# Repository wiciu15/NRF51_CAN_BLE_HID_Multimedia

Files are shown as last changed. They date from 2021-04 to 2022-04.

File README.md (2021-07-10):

#### *TLDR: Controlling spotify on the phone, with car's CAN bus*

This project is a ***work in progress***. Comes with no warranty. Vehicles CAN-bus is a powerful tool, ***use at your own risk***, author does not have responsibility for any damage on property or health.

Intended for ***2011-2013 Chevrolet Volt***, may work with other General Motors Global Platform A cars.
Uses own ***MCP2515 CAN controller*** chip library to interact with CAN-bus (Low-speed SWCAN/GMLAN in General Motors Vehicles).

Nordic ***NRF51822 microcontroler*** is in charge of Bluetooth LE connection and HID protocol.
HID report descriptor is custom and supports only 7 consumer control(multimedia) keys, like Play/Pause, Scan Next, Scan Prev, Mute.

CAN frames processing is offloaded to MCP2515 with usage of filters, to reduce uC usage and energy efficiency.
While MCP2515 is used in normal operating mode, device should not transmit anything other than error/ack frames.

PCB design needs some fixes and further testing. As of this moment 16Mhz crystal footprint is mirrored, MCP2515 INT pin needs a pullup resistor and SWDIO/RST pullup+optional power-on-reset 2.2u capacitor.

**[Project log on hackaday.io](https://hackaday.io/project/176834-chevy-volt-sw-can-ble-multimedia-control)**

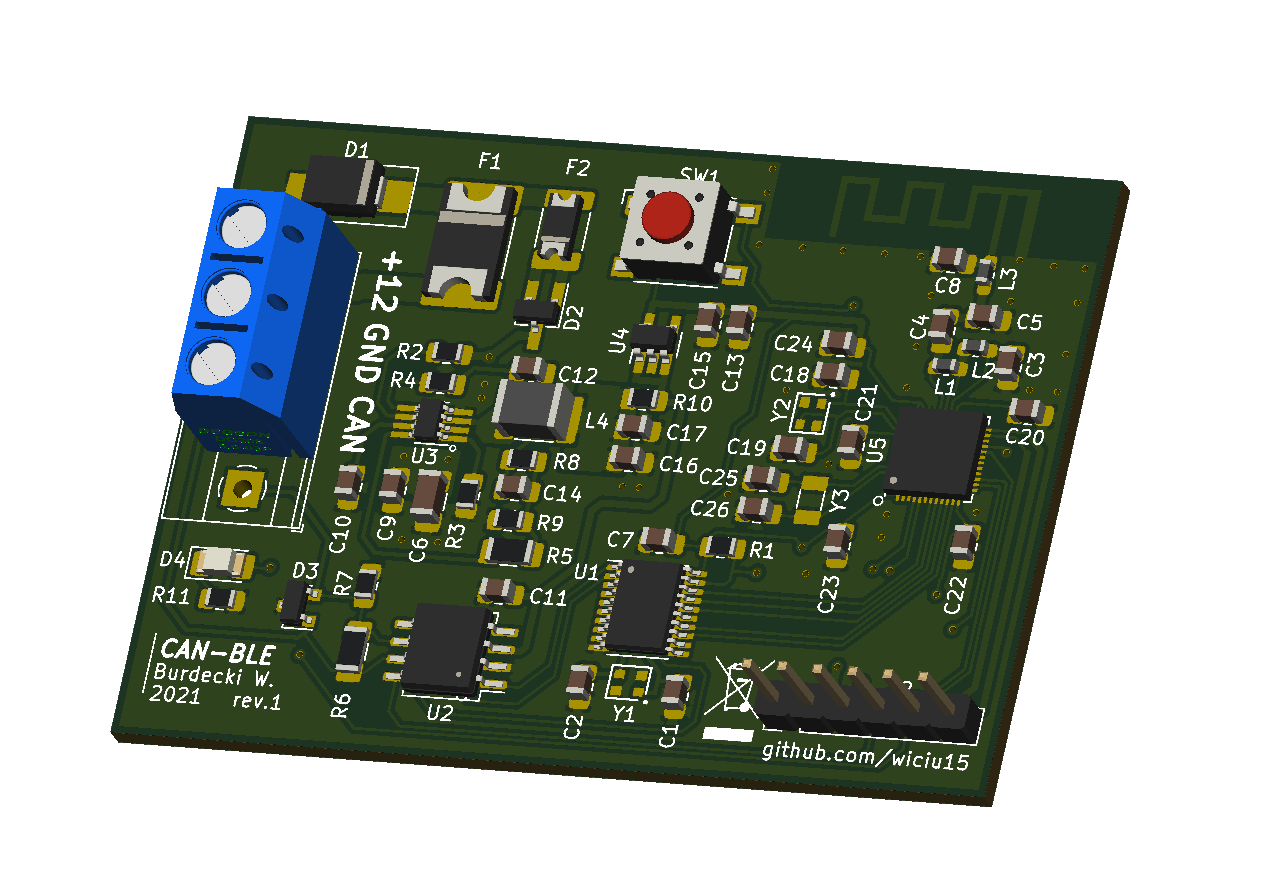
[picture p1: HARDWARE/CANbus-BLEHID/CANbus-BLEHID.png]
PCB render


Provided files are Eclipse GNU MCU Embedded project. To build it you need to also provide NRF SDK v12.3 (include directories), GCC arm-none-eabi compiler, and OpenOCD to use flash script (flash.bat file) with ST-Link v2 SWD programmer.

Software contains code from linux kernel CAN driver, and open-usb-can project by Fabio Baltieri.

**Software licensed under GNU General Public License v3.**
This program is free software: you can redistribute it and/or modify
it under the terms of the GNU General Public License as published by
the Free Software Foundation, either version 3 of the License, or
(at your option) any later version.

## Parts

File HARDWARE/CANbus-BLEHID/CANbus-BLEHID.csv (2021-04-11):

Source: | C:\NRFdev\projekty\NRF51_CAN_BLE_HID_Multimedia\HARDWARE\CANbus-BLEHID\CANbus-BLEHID.sch
Date: | 10.04.2021 16:22:58
Tool: | Eeschema (5.1.6)-1
Generator: | C:\Program Files\KiCad\bin\scripting\plugins/bom_csv_grouped_by_value_with_fp.py
Component Count: | 59
Ref | Qnty | Value | Cmp name | Footprint | Description | Vendor
AE1, | 1 | 2.45 GHz PCB antenna | Antenna | RF_Antenna:Texas_SWRA117D_2.4GHz_Right | Antenna
C1, C2, C14, C18, C19, C25, C26, | 7 | 12pF | C_Small | Capacitor_SMD:C_0805_2012Metric_Pad1.15x1.40mm_HandSolder | Unpolarized capacitor, small symbol
C3, | 1 | 2.2n | C_Small | Capacitor_SMD:C_0805_2012Metric_Pad1.15x1.40mm_HandSolder | Unpolarized capacitor, small symbol
C4, | 1 | 3.9p | C_Small | Capacitor_SMD:C_0805_2012Metric_Pad1.15x1.40mm_HandSolder | Unpolarized capacitor, small symbol
C5, | 1 | 1p | C_Small | Capacitor_SMD:C_0805_2012Metric_Pad1.15x1.40mm_HandSolder | Unpolarized capacitor, small symbol
C6, | 1 | 10u 16V | CP | Capacitor_SMD:C_1206_3216Metric_Pad1.42x1.75mm_HandSolder | Polarized capacitor
C7, C9, C10, C11, C12, C15, C17, C20, C21, C22, C23, | 11 | 100n | C_Small | Capacitor_SMD:C_0805_2012Metric_Pad1.15x1.40mm_HandSolder | Unpolarized capacitor, small symbol
C8, | 1 | 1.5p | C_Small | Capacitor_SMD:C_0805_2012Metric_Pad1.15x1.40mm_HandSolder | Unpolarized capacitor, small symbol
C13, C16, | 2 | 22u 6,3V | CP | Capacitor_SMD:C_0805_2012Metric_Pad1.15x1.40mm_HandSolder | Polarized capacitor
C24, | 1 | 1n | C_Small | Capacitor_SMD:C_0805_2012Metric_Pad1.15x1.40mm_HandSolder | Unpolarized capacitor, small symbol
D1, | 1 | SM6T15CA | D_Zener_ALT | Diode_SMD:D_SMB_Handsoldering | Zener diode, filled shape
D2, | 1 | BAV70 | D_AAK | Package_TO_SOT_SMD:SOT-23_Handsoldering | Diode, anode on pins 1 and 2
D3, | 1 | PESD1CAN | NUP2105L | Package_TO_SOT_SMD:SOT-23 | Dual Line CAN Bus Protector, 24Vrwm
D4, | 1 | LED | LED | LED_SMD:LED_1206_3216Metric_Pad1.42x1.75mm_HandSolder | Light emitting diode
F1, | 1 | 0ZCF0200AF2C | Polyfuse_Small | Fuse:Fuse_2920_7451Metric_Pad2.10x5.45mm_HandSolder | Resettable fuse, polymeric positive temperature coefficient, small symbol
F2, | 1 | 0ZCK0010FF2G | Polyfuse_Small | Fuse:Fuse_1812_4532Metric_Pad1.30x3.40mm_HandSolder | Resettable fuse, polymeric positive temperature coefficient, small symbol
J1, | 1 | AC300V-04P-5.0 | Screw_Terminal_01x04 | TerminalBlock:TerminalBlock_Altech_AK300-4_P5.00mm | Generic screw terminal, single row, 01x04, script generated (kicad-library-utils/schlib/autogen/connector/)
J2, | 1 | UART | Conn_01x06_Male | Connector_PinHeader_2.54mm:PinHeader_1x06_P2.54mm_Vertical | Generic connector, single row, 01x06, script generated (kicad-library-utils/schlib/autogen/connector/)
L1, | 1 | 4.7n | L | Inductor_SMD:L_0603_1608Metric_Pad1.05x0.95mm_HandSolder | Inductor
L2, | 1 | 27n | L | Inductor_SMD:L_0603_1608Metric_Pad1.05x0.95mm_HandSolder | Inductor
L3, | 1 | 3.3n | L | Inductor_SMD:L_0603_1608Metric_Pad1.05x0.95mm_HandSolder | Inductor
L4, | 1 | NL12KTC5R6 | L | Inductor_SMD:L_1812_4532Metric_Pad1.30x3.40mm_HandSolder | Inductor
R1, | 1 | 10k | R_Small | Resistor_SMD:R_0805_2012Metric_Pad1.15x1.40mm_HandSolder | Resistor, small symbol
R2, R3, | 2 | 75k | R_Small | Resistor_SMD:R_0805_2012Metric_Pad1.15x1.40mm_HandSolder | Resistor, small symbol
R4, | 1 | 20R | R_Small | Resistor_SMD:R_0805_2012Metric_Pad1.15x1.40mm_HandSolder | Resistor, small symbol
R5, | 1 | 20k | R_Small | Resistor_SMD:R_1206_3216Metric_Pad1.42x1.75mm_HandSolder | Resistor, small symbol
R6, | 1 | 120R | R_Small | Resistor_SMD:R_1206_3216Metric_Pad1.42x1.75mm_HandSolder | Resistor, small symbol
R7, R10, | 2 | 0R | R_Small | Resistor_SMD:R_0805_2012Metric_Pad1.15x1.40mm_HandSolder | Resistor, small symbol
R8, | 1 | 40,2k | R_Small | Resistor_SMD:R_0805_2012Metric_Pad1.15x1.40mm_HandSolder | Resistor, small symbol
R9, | 1 | 7,5k | R_Small | Resistor_SMD:R_0805_2012Metric_Pad1.15x1.40mm_HandSolder | Resistor, small symbol
R11, | 1 | 1k | R_Small | Resistor_SMD:R_0805_2012Metric_Pad1.15x1.40mm_HandSolder | Resistor, small symbol
SW1, | 1 | SW_Push_Dual | SW_Push_Dual | Button_Switch_SMD:SW_SPST_Omron_B3FS-100xP | Push button switch, generic, symbol, four pins
U1, | 1 | MCP2515-xST | MCP2515-xST | Package_SO:TSSOP-20_4.4x6.5mm_P0.65mm | Stand-Alone CAN Controller with SPI Interface, TSSOP-20
U2, | 1 | TLE7250V | TLE7250V | Package_SO:SO-8_5.3x6.2mm_P1.27mm
U3, | 1 | MP2315GJ-Z | MP2315GJ-Z | Package_TO_SOT_SMD:TSOT-23-8_HandSoldering | przetwornica DC/DC; Upracy: 4,5÷24V; Uwyj: 0,8÷22,8V; buck
U4, | 1 | MIC5504-3.3YM5 | MIC5504-3.3YM5 | Package_TO_SOT_SMD:SOT-23-5_HandSoldering | 300mA Low-dropout Voltage Regulator, Vout 3.3V, Vin up to 5.5V, SOT-23
U5, | 1 | nRF51822-QFAC | nRF51x22-QFxx | Package_DFN_QFN:QFN-48-1EP_6x6mm_P0.4mm_EP4.6x4.6mm | Multiprotocol BLE/2.4GHz Cortex-M0+ SoC
Y1, Y2, | 2 | 16M | Crystal | XT224-16:XT224-16 | Two pin crystal
Y3, | 1 | 32,768k | Crystal | Crystal:Crystal_SMD_3215-2Pin_3.2x1.5mm | Two pin crystal

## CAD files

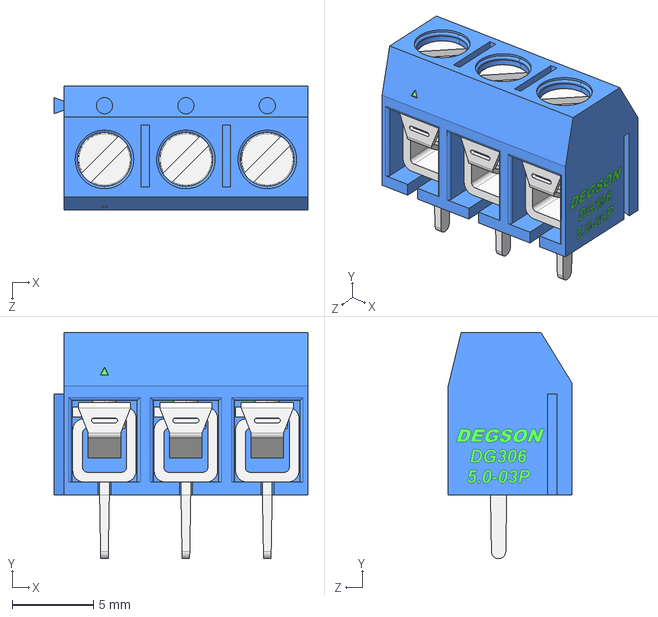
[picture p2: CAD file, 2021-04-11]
HARDWARE/CANbus-BLEHID/DG306-5.0-03P-12-00AH.STEP
15.6 x 13.9 x 7.60 mm

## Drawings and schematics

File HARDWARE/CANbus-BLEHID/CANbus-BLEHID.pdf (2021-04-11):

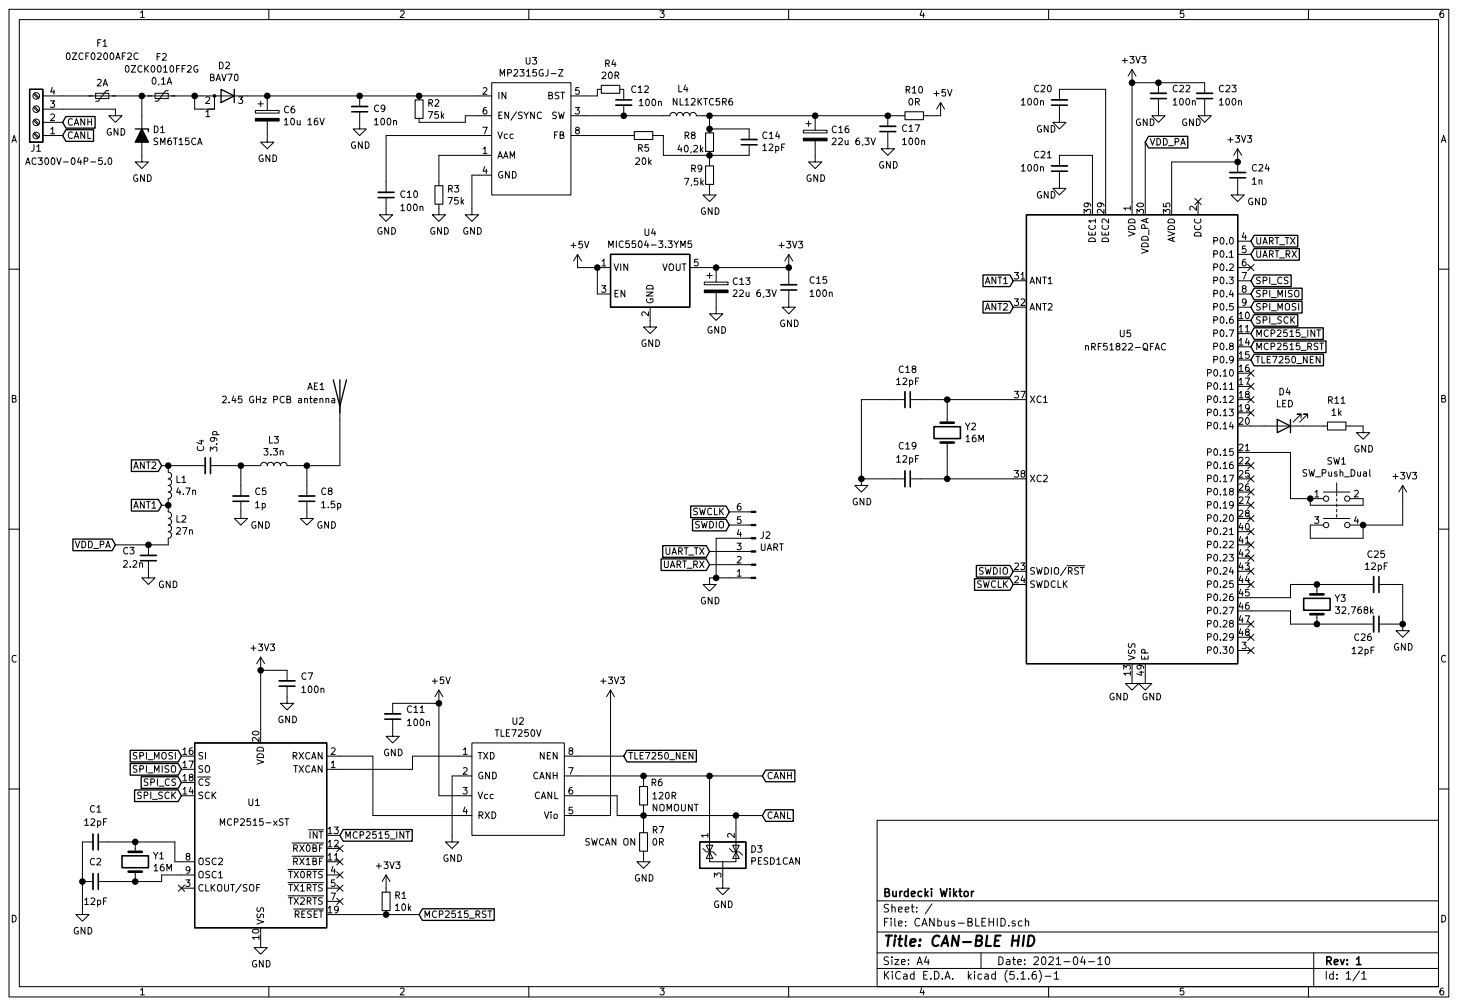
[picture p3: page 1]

2 EN 3 VOUT 5 U4 MIC5504-3.3YM5 +5V GND GND

2 P0.14 20 P0.15 21 P0.16 22 SWDIO/RST 23 SWDCLK 24 P0.17 25 P0.18 26 P0.19 27 P0.20 28 DEC2 29 P0.30 3 VDD_PA 30 ANT1 31 ANT2 32 AVDD 35 XC1 37 XC2 38 DEC1 39 P0.0 4 P0.21 40 P0.22 41 P0.23 42 P0.24 43 P0.25 44 P0.26 45 P0.27 46 P0.28 47 P0.29 48 EP 49 P0.1 5 P0.2 6 P0.3 7 P0.4 8 P0.5 9 U5

Id: 1/1 Title: CAN-BLE HID

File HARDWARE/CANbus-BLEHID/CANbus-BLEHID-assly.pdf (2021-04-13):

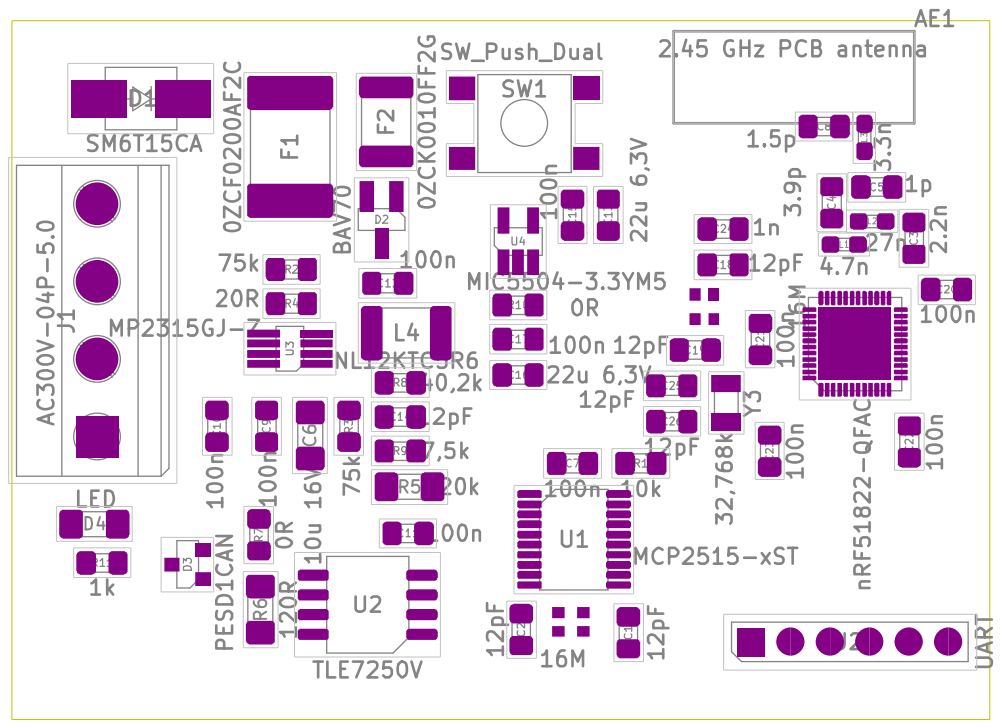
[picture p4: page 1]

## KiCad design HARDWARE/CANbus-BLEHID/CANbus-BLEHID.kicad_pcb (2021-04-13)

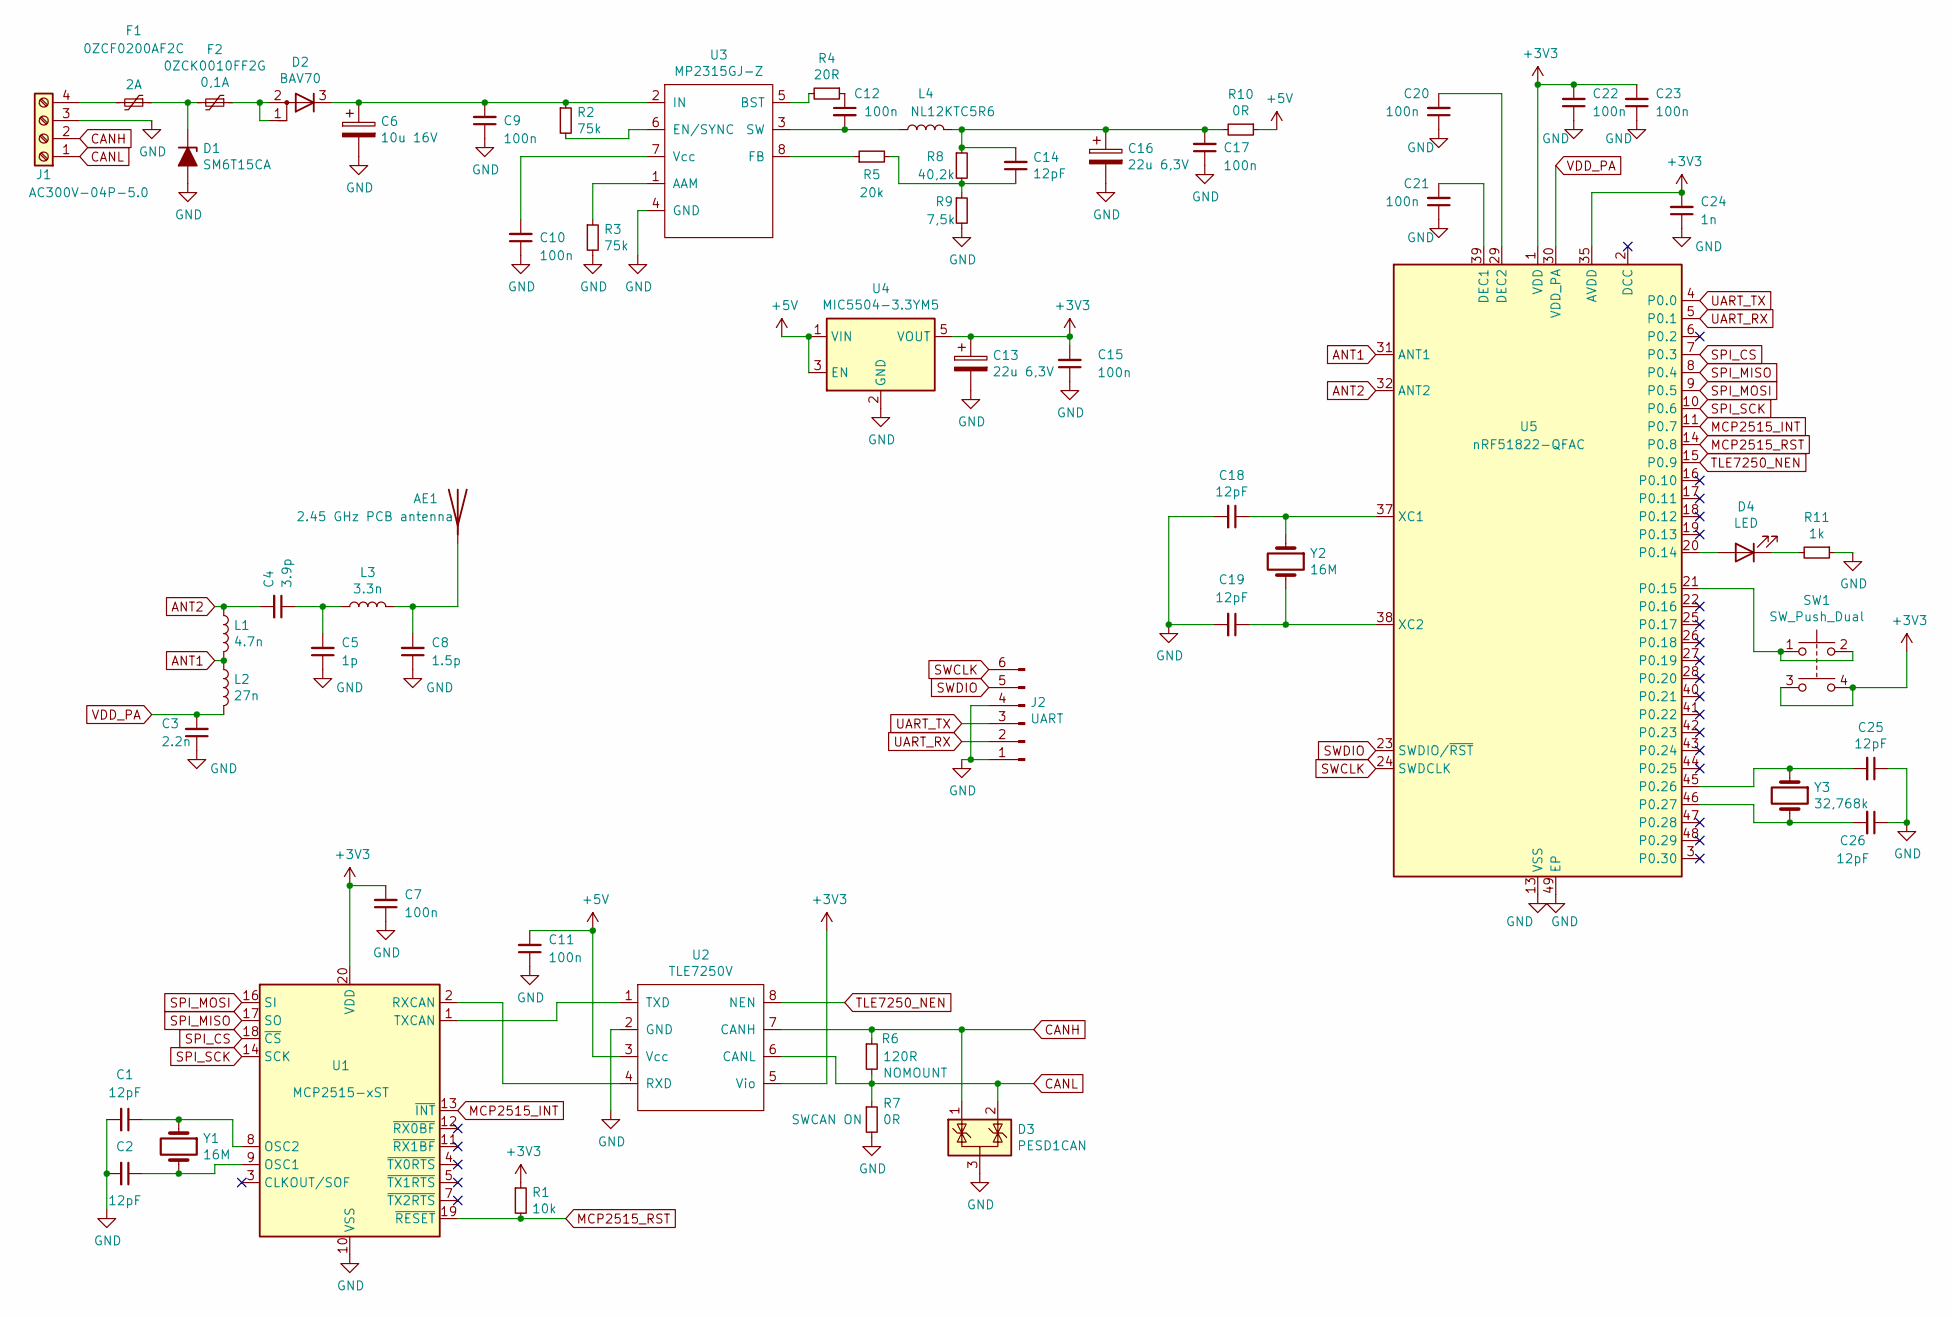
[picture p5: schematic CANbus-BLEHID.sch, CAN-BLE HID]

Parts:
AE1: 2.45 GHz PCB antenna; Texas_SWRA117D_2.4GHz_Left
C1, C2, C14, C18, C19, C25, C26: 12pF; C_0805_2012Metric_Pad1.15x1.40mm_HandSolder
C3: 2.2n; C_0805_2012Metric_Pad1.15x1.40mm_HandSolder
C4: 3.9p; C_0805_2012Metric_Pad1.15x1.40mm_HandSolder
C5: 1p; C_0805_2012Metric_Pad1.15x1.40mm_HandSolder
C6: 10u 16V; C_1206_3216Metric_Pad1.42x1.75mm_HandSolder
C7, C9, C10, C11, C12, C15, C17, C20, C21, C22, C23: 100n; C_0805_2012Metric_Pad1.15x1.40mm_HandSolder
C8: 1.5p; C_0805_2012Metric_Pad1.15x1.40mm_HandSolder
C13, C16: 22u 6,3V; C_0805_2012Metric_Pad1.15x1.40mm_HandSolder
C24: 1n; C_0805_2012Metric_Pad1.15x1.40mm_HandSolder
D1: SM6T15CA; D_SMB_Handsoldering
D2: BAV70; SOT-23_Handsoldering
D3: PESD1CAN; SOT-23
D4: LED; LED_1206_3216Metric_Pad1.42x1.75mm_HandSolder
F1: 0ZCF0200AF2C; Fuse_2920_7451Metric_Pad2.10x5.45mm_HandSolder
F2: 0ZCK0010FF2G; Fuse_1812_4532Metric_Pad1.30x3.40mm_HandSolder
J1: AC300V-04P-5.0; TerminalBlock_Phoenix_MKDS-1,5-4_1x04_P5.00mm_Horizontal
J2: UART; PinHeader_1x06_P2.54mm_Vertical
L1: 4.7n; L_0603_1608Metric_Pad1.05x0.95mm_HandSolder
L2: 27n; L_0603_1608Metric_Pad1.05x0.95mm_HandSolder
L3: 3.3n; L_0603_1608Metric_Pad1.05x0.95mm_HandSolder
L4: NL12KTC5R6; L_1812_4532Metric_Pad1.30x3.40mm_HandSolder
R1: 10k; R_0805_2012Metric_Pad1.15x1.40mm_HandSolder
R2, R3: 75k; R_0805_2012Metric_Pad1.15x1.40mm_HandSolder
R4: 20R; R_0805_2012Metric_Pad1.15x1.40mm_HandSolder
R5: 20k; R_1206_3216Metric_Pad1.42x1.75mm_HandSolder
R6: 120R; R_1206_3216Metric_Pad1.42x1.75mm_HandSolder
R7, R10: 0R; R_0805_2012Metric_Pad1.15x1.40mm_HandSolder
R8: 40,2k; R_0805_2012Metric_Pad1.15x1.40mm_HandSolder
R9: 7,5k; R_0805_2012Metric_Pad1.15x1.40mm_HandSolder
R11: 1k; R_0805_2012Metric_Pad1.15x1.40mm_HandSolder
SW1: SW_Push_Dual; SW_SPST_Omron_B3FS-100xP
U1: MCP2515-xST; TSSOP-20_4.4x6.5mm_P0.65mm
U2: TLE7250V; SO-8_5.3x6.2mm_P1.27mm
U3: MP2315GJ-Z; TSOT-23-8_HandSoldering
U4: MIC5504-3.3YM5; SOT-23-5_HandSoldering
U5: nRF51822-QFAC; QFN-48-1EP_6x6mm_P0.4mm_EP4.6x4.6mm
Y1, Y2: 16M; XT224-16
Y3: 32,768k; Crystal_SMD_3215-2Pin_3.2x1.5mm

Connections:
+3V3: C7.2, C13.1, C15.2, C22.2, C23.2, C24.2, R1.1, SW1.3, SW1.4, U1.20 (VDD), U2.5 (Vio), U4.5 (VOUT), U5.1 (VDD), U5.12 (VDD), U5.35 (AVDD), U5.36 (AVDD)
+5V: C11.2, R10.1, U2.3 (Vcc), U4.1 (VIN), U4.3 (EN)
ANT1: L1.2, L2.1, U5.31 (ANT1)
ANT2: C4.2, L1.1, U5.32 (ANT2)
CANH: D3.1 (K), J1.2, R6.1, U2.7 (CANH)
CANL: D3.2 (K), J1.1, R6.2, R7.1, U2.6 (CANL)
GND: AE1.2, C1.2, C2.2, C3.1, C5.1, C6.2, C7.1, C8.1, C9.1, C10.1, C11.1, C13.2, C15.1, C16.2, C17.1, C18.2, C19.2, C20.1, C21.1, C22.1, C23.1, C24.1, C25.1, C26.1, D1.2 (A), D3.3 (A), J1.3, J2.1, J2.4, R3.2, R7.2, R9.2, R11.1, U1.10 (VSS), U2.2 (GND), U3.4 (GND), U4.2 (GND), U5.13 (VSS), U5.33 (VSS), U5.34 (VSS), U5.49 (EP)
MCP2515_INT: U1.13 (~INT), U5.11 (P0.7)
MCP2515_RST: R1.2, U1.19 (~RESET), U5.14 (P0.8)
unnamed: AE1.1, C8.2, L3.2
unnamed: C1.1, U1.8 (OSC2), Y1.1
unnamed: C2.1, U1.9 (OSC1), Y1.2
unnamed: C4.1, C5.2, L3.1
unnamed: C6.1, C9.2, D2.3 (K), R2.1, U3.2 (IN)
unnamed: C10.2, U3.7 (Vcc)
unnamed: C12.1, R4.1
unnamed: C12.2, L4.1, U3.3 (SW)
unnamed: C14.1, R5.2, R8.2, R9.1
unnamed: C14.2, C16.1, C17.2, L4.2, R8.1, R10.2
unnamed: C18.1, U5.37 (XC1), Y2.1
unnamed: C19.1, U5.38 (XC2), Y2.2
unnamed: C20.2, U5.29 (DEC2)
unnamed: C21.2, U5.39 (DEC1)
unnamed: C25.2, U5.45 (P0.26), Y3.1
unnamed: C26.2, U5.46 (P0.27), Y3.2
unnamed: D1.1 (K), F1.1, F2.2
unnamed: D2.1 (A), D2.2 (A), F2.1
unnamed: D4.1 (K), R11.2
unnamed: D4.2 (A), U5.20 (P0.14)
unnamed: F1.2, J1.4
unnamed: R2.2, U3.6 (EN/SYNC)
unnamed: R3.1, U3.1 (AAM)
unnamed: R4.2, U3.5 (BST)
unnamed: R5.1, U3.8 (FB)
unnamed: SW1.1, SW1.2, U5.21 (P0.15)
unnamed: U1.1 (TXCAN), U2.1 (TXD)
unnamed: U1.2 (RXCAN), U2.4 (RXD)
SPI_CS: U1.18 (~CS), U5.7 (P0.3)
SPI_MISO: U1.17 (SO), U5.8 (P0.4)
SPI_MOSI: U1.16 (SI), U5.9 (P0.5)
SPI_SCK: U1.14 (SCK), U5.10 (P0.6)
SWCLK: J2.6, U5.24 (SWDCLK)
SWDIO: J2.5, U5.23 (SWDIO/~RST)
TLE7250_NEN: U2.8 (NEN), U5.15 (P0.9)
UART_RX: J2.2, U5.5 (P0.1)
UART_TX: J2.3, U5.4 (P0.0)
VDD_PA: C3.2, L2.2, U5.30 (VDD_PA)

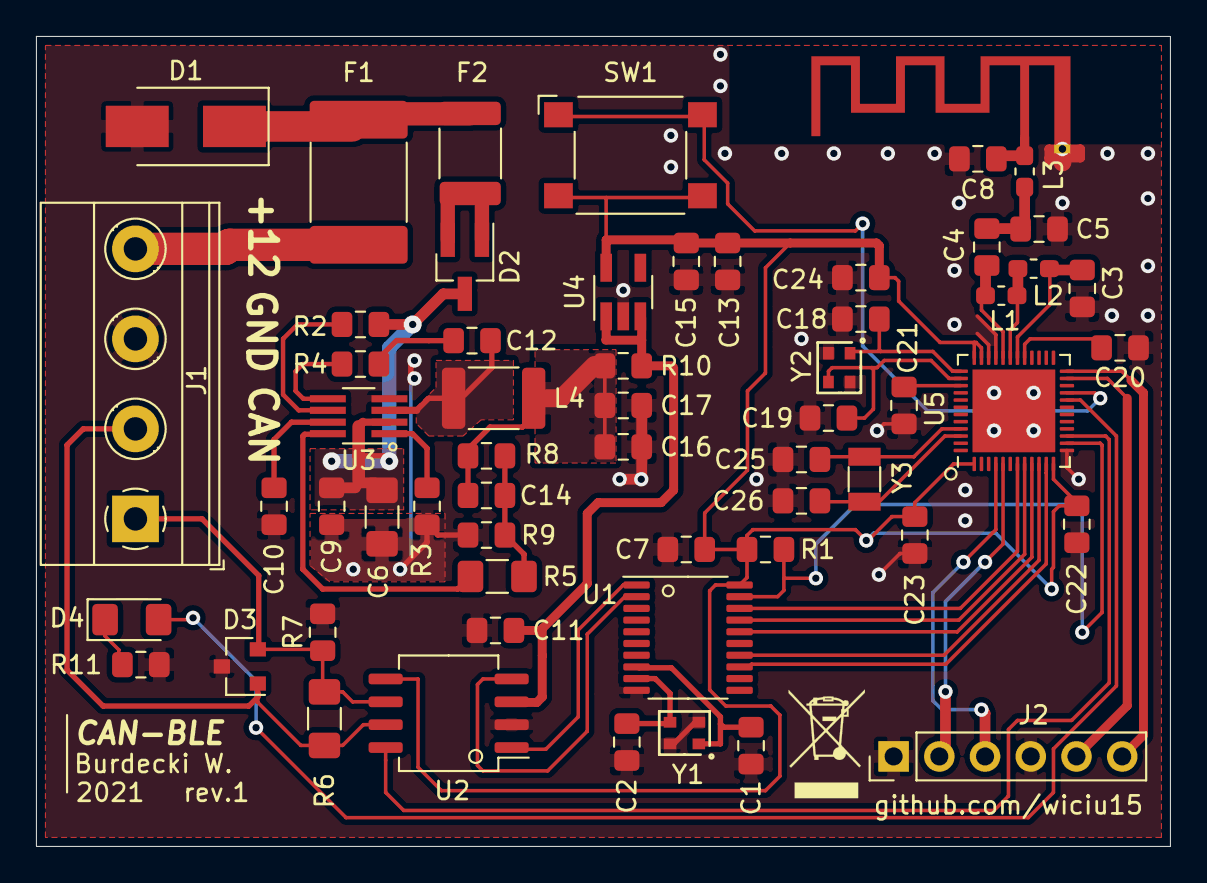
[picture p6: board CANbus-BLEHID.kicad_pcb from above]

Board: 2 copper layers, 63.0 x 45.0 mm, 59 parts (0 on the bottom side), 47 nets.

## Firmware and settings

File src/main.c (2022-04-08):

/**
 * Copyright (c) 2012 - 2017, Nordic Semiconductor ASA
 *
 * All rights reserved.
 *
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
 * 3. Neither the name of Nordic Semiconductor ASA nor the names of its
 *    contributors may be used to endorse or promote products derived from this
 *    software without specific prior written permission.
 *
 * 4. This software, with or without modification, must only be used with a
 *    Nordic Semiconductor ASA integrated circuit.
 *
 * 5. Any software provided in binary form under this license must not be reverse
 *    engineered, decompiled, modified and/or disassembled.
 *
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
 */

/** @file

 * @brief Main file of CANbus-BLE HID Multimedia Keyboard
 *
 * This file contains the source code for application using the BLE HID Keyboard to send consumer(multimedia) keys to a paired device
 * based on received CANbus messages
 * BLE HID part is heavily based on ble_app_hids_keyboard example from NRFDSK12 and used under its conditions.
 * This project features basic and lightweight MCP2515 SPI-CAN controller library,
 * inspired by MCP2515 arduino library and headers from open-usb-can project by @fabiobaltieri.
 * CAN message handling in software is based on the way linux kernel handles it.
 *
 * This program is free software: you can redistribute it and/or modify
 * it under the terms of the GNU General Public License as published by
 * the Free Software Foundation, either version 3 of the License, or
 * (at your option) any later version.
 */

#include <stdint.h>
#include <string.h>
#include "nordic_common.h"
#include "nrf.h"
#include "nrf_assert.h"
#include "app_error.h"
#include "nrf_gpio.h"
#include "ble.h"
#include "ble_hci.h"
#include "ble_srv_common.h"
#include "ble_advertising.h"
#include "ble_advdata.h"
#include "ble_hids.h"
#include "ble_bas.h"
#include "ble_dis.h"
#include "ble_conn_params.h"
#include "app_scheduler.h"
#include "softdevice_handler_appsh.h"
#include "app_timer_appsh.h"
#include "peer_manager.h"
#include "fds.h"
#include "fstorage.h"
#include "ble_conn_state.h"
#include "nrf_drv_gpiote.h"

#include "can.h"
#include "mcp2515.h"
#include "hid_mmkeys.h"


#define NRF_LOG_MODULE_NAME "APP"
#include "nrf_log.h"
#include "nrf_log_ctrl.h"

#if (NRF_SD_BLE_API_VERSION == 3)
#define NRF_BLE_MAX_MTU_SIZE            GATT_MTU_SIZE_DEFAULT                       /**< MTU size used in the softdevice enabling and to reply to a BLE_GATTS_EVT_EXCHANGE_MTU_REQUEST event. */
#endif

#define CENTRAL_LINK_COUNT               0                                          /**< Number of central links used by the application. When changing this number remember to adjust the RAM settings*/
#define PERIPHERAL_LINK_COUNT            1                                          /**< Number of peripheral links used by the application. When changing this number remember to adjust the RAM settings*/

#define UART_TX_BUF_SIZE                 256                                        /**< UART TX buffer size. */
#define UART_RX_BUF_SIZE                 1                                          /**< UART RX buffer size. */

#define DEVICE_NAME                      "Multimedia"                      		    /**< Name of device. Will be included in the advertising data. */
#define MANUFACTURER_NAME                "None"                   				    /**< Manufacturer. Will be passed to Device Information Service. */

#define APP_TIMER_PRESCALER              0                                          /**< Value of the RTC1 PRESCALER register. */
#define APP_TIMER_OP_QUEUE_SIZE          4                                          /**< Size of timer operation queues. */

#define BATTERY_LEVEL_MEAS_INTERVAL      APP_TIMER_TICKS(2000, APP_TIMER_PRESCALER) /**< Battery level measurement interval (ticks). */
#define KEY_RELEASE_REPORT_INTERVAL		 APP_TIMER_TICKS(30,APP_TIMER_PRESCALER)
#define DELAY_BEFORE_SLEEP				 APP_TIMER_TICKS(30000,APP_TIMER_PRESCALER) /**< ms before MCP2515 going to sleep mode after BLE disconnected */
#define START_PLAYING_DELAY				 APP_TIMER_TICKS(5000,APP_TIMER_PRESCALER)  /**< ms after BLE connect event, that play button report is sent */
#define LED_BLINK_TIME					 APP_TIMER_TICKS(100,APP_TIMER_PRESCALER)	/**< lenght of activity led blink*/
#define HOLD_TO_ERASE_BONDS_DELAY		 APP_TIMER_TICKS(3000,APP_TIMER_PRESCALER)	/**< how long is a key press needed to start bond erasing and pairing to new device */
#define DEBOUNCE_DELAY				     APP_TIMER_TICKS(200,APP_TIMER_PRESCALER)

#define PNP_ID_VENDOR_ID_SOURCE          0x01                                       /**< Vendor ID Source. */
#define PNP_ID_VENDOR_ID                 0xFFFF                                     /**< Vendor ID. */
#define PNP_ID_PRODUCT_ID                0xEEEE                                     /**< Product ID. */
#define PNP_ID_PRODUCT_VERSION           0x0001                                     /**< Product Version. */

#define APP_ADV_FAST_INTERVAL            0x0028                                     /**< Fast advertising interval (in units of 0.625 ms. This value corresponds to 25 ms.). */
#define APP_ADV_SLOW_INTERVAL            0x0C80                                     /**< Slow advertising interval (in units of 0.625 ms. This value corrsponds to 2 seconds). */
#define APP_ADV_FAST_TIMEOUT             30                                         /**< The duration of the fast advertising period (in seconds). */
#define APP_ADV_SLOW_TIMEOUT             0                                          /**< The duration of the slow advertising period (in seconds). */

/*lint -emacro(524, MIN_CONN_INTERVAL) // Loss of precision */
#define MIN_CONN_INTERVAL                MSEC_TO_UNITS(7.5, UNIT_1_25_MS)            /**< Minimum connection interval (7.5 ms) */
#define MAX_CONN_INTERVAL                MSEC_TO_UNITS(30, UNIT_1_25_MS)             /**< Maximum connection interval (30 ms). */
#define SLAVE_LATENCY                    6                                           /**< Slave latency. */
#define CONN_SUP_TIMEOUT                 MSEC_TO_UNITS(430, UNIT_10_MS)              /**< Connection supervisory timeout (430 ms). */

#define FIRST_CONN_PARAMS_UPDATE_DELAY   APP_TIMER_TICKS(5000, APP_TIMER_PRESCALER)  /**< Time from initiating event (connect or start of notification) to first time sd_ble_gap_conn_param_update is called (5 seconds). */
#define NEXT_CONN_PARAMS_UPDATE_DELAY    APP_TIMER_TICKS(30000, APP_TIMER_PRESCALER) /**< Time between each call to sd_ble_gap_conn_param_update after the first call (30 seconds). */
#define MAX_CONN_PARAMS_UPDATE_COUNT     3                                           /**< Number of attempts before giving up the connection parameter negotiation. */

#define SEC_PARAM_BOND                   1                                           /**< Perform bonding. */
#define SEC_PARAM_MITM                   0                                           /**< Man In The Middle protection not required. */
#define SEC_PARAM_LESC                   0                                           /**< LE Secure Connections not enabled. */
#define SEC_PARAM_KEYPRESS               0                                           /**< Keypress notifications not enabled. */
#define SEC_PARAM_IO_CAPABILITIES        BLE_GAP_IO_CAPS_NONE                        /**< No I/O capabilities. */
#define SEC_PARAM_OOB                    0                                           /**< Out Of Band data not available. */
#define SEC_PARAM_MIN_KEY_SIZE           7                                           /**< Minimum encryption key size. */
#define SEC_PARAM_MAX_KEY_SIZE           16                                          /**< Maximum encryption key size. */

#define INPUT_REPORT_KEYS_INDEX          0                                           /**< Index of Input Report. */
#define INPUT_REP_REF_ID                 0                                           /**< Id of reference to Keyboard Input Report. */

#define APP_FEATURE_NOT_SUPPORTED        BLE_GATT_STATUS_ATTERR_APP_BEGIN + 2        /**< Reply when unsupported features are requested. */

#define MAX_BUFFER_ENTRIES               5                                           /**< Number of elements that can be enqueued */

#define BASE_USB_HID_SPEC_VERSION        0x0101                                      /**< Version number of base USB HID Specification implemented by this application. */

#define INPUT_REPORT_KEYS_MAX_LEN        2                                           /**< Maximum length of the Input Report characteristic. */

#define DEAD_BEEF                        0xDEADBEEF                                  /**< Value used as error code on stack dump, can be used to identify stack location on stack unwind. */

#define RESET_BONDS_BUTTON_PIN			 15
#define ONBOARD_LED_PIN					 14
#define SCHED_MAX_EVENT_DATA_SIZE        MAX(APP_TIMER_SCHED_EVT_SIZE, \
                                             BLE_STACK_HANDLER_SCHED_EVT_SIZE)       /**< Maximum size of scheduler events. */
#ifdef SVCALL_AS_NORMAL_FUNCTION
#define SCHED_QUEUE_SIZE                 20                                          /**< Maximum number of events in the scheduler queue. More is needed in case of Serialization. */
#else
#define SCHED_QUEUE_SIZE                 10                                          /**< Maximum number of events in the scheduler queue. */
#endif

#define NRF_CLOCK_LFCLKSRC      {.source        = NRF_CLOCK_LF_SRC_RC,            \
                                 .rc_ctiv       = 8,                                \
                                 .rc_temp_ctiv  = 0,                                \
                                 .xtal_accuracy = NRF_CLOCK_LF_XTAL_ACCURACY_20_PPM}

typedef enum
{
    BLE_NO_ADV,             /**< No advertising running. */
    BLE_DIRECTED_ADV,       /**< Direct advertising to the latest central. */
    BLE_FAST_ADV_WHITELIST, /**< Advertising with whitelist. */
    BLE_FAST_ADV,           /**< Fast advertising running. */
    BLE_SLOW_ADV,           /**< Slow advertising running. */
    BLE_SLEEP,              /**< Go to system-off. */
} ble_advertising_mode_t;

static ble_hids_t m_hids;                                   /**< Structure used to identify the HID service. */
static ble_bas_t  m_bas;                                    /**< Structure used to identify the battery service. */
static bool       m_in_boot_mode = false;                   /**< Current protocol mode. */
static uint16_t   m_conn_handle  = BLE_CONN_HANDLE_INVALID; /**< Handle of the current connection. */

struct can_frame received_can_frame;						/** buffer to store received can frame*/
uint8_t inhibit_button_press=0;

APP_TIMER_DEF(m_battery_timer_id);                          /**< Battery timer. */
APP_TIMER_DEF(m_key_release_interval_id);
APP_TIMER_DEF(m_sleep_delay_timer_id);
APP_TIMER_DEF(m_start_playing_timer_id);
APP_TIMER_DEF(m_blink); //activity and status led
APP_TIMER_DEF(m_adv_blink); //blinking when advertising
APP_TIMER_DEF(m_hold_to_erase_bonds_timer); //hold button on steering wheel to erase all bonds and reset
APP_TIMER_DEF(m_steering_wheel_switch_debounce_timer);//delay to ignore bouncing switch and switching 2 songs in a row

static pm_peer_id_t m_peer_id;                              /**< Device reference handle to the current bonded central. */

static pm_peer_id_t   m_whitelist_peers[BLE_GAP_WHITELIST_ADDR_MAX_COUNT];  /**< List of peers currently in the whitelist. */
static uint32_t       m_whitelist_peer_cnt;                                 /**< Number of peers currently in the whitelist. */
static bool           m_is_wl_changed;                                      /**< Indicates if the whitelist has been changed since last time it has been updated in the Peer Manager. */

static ble_uuid_t m_adv_uuids[] = {{BLE_UUID_HUMAN_INTERFACE_DEVICE_SERVICE, BLE_UUID_TYPE_BLE}};

/** List to enqueue not just data to be sent, but also related information like the handle, connection handle etc */


static void on_hids_evt(ble_hids_t * p_hids, ble_hids_evt_t * p_evt);

/**@brief Callback function for asserts in the SoftDevice.
 *
 * @details This function will be called in case of an assert in the SoftDevice.
 *
 * @warning This handler is an example only and does not fit a final product. You need to analyze
 *          how your product is supposed to react in case of Assert.
 * @warning On assert from the SoftDevice, the system can only recover on reset.
 *
 * @param[in]   line_num   Line number of the failing ASSERT call.
 * @param[in]   file_name  File name of the failing ASSERT call.
 */
void assert_nrf_callback(uint16_t line_num, const uint8_t * p_file_name)
{
    app_error_handler(DEAD_BEEF, line_num, p_file_name);
}


/**@brief Fetch the list of peer manager peer IDs.
 *
 * @param[inout] p_peers   The buffer where to store the list of peer IDs.
 * @param[inout] p_size    In: The size of the @p p_peers buffer.
 *                         Out: The number of peers copied in the buffer.
 */
static void peer_list_get(pm_peer_id_t * p_peers, uint32_t * p_size)
{
    pm_peer_id_t peer_id;
    uint32_t     peers_to_copy;

    peers_to_copy = (*p_size < BLE_GAP_WHITELIST_ADDR_MAX_COUNT) ?
                     *p_size : BLE_GAP_WHITELIST_ADDR_MAX_COUNT;

    peer_id = pm_next_peer_id_get(PM_PEER_ID_INVALID);
    *p_size = 0;

    while ((peer_id != PM_PEER_ID_INVALID) && (peers_to_copy--))
    {
        p_peers[(*p_size)++] = peer_id;
        peer_id = pm_next_peer_id_get(peer_id);
    }
}


/**@brief Function for starting advertising.
 */
static void advertising_start(void)
{
    ret_code_t ret;

    memset(m_whitelist_peers, PM_PEER_ID_INVALID, sizeof(m_whitelist_peers));
    m_whitelist_peer_cnt = (sizeof(m_whitelist_peers) / sizeof(pm_peer_id_t));

    peer_list_get(m_whitelist_peers, &m_whitelist_peer_cnt);

    ret = pm_whitelist_set(m_whitelist_peers, m_whitelist_peer_cnt);
    APP_ERROR_CHECK(ret);

    // Setup the device identies list.
    // Some SoftDevices do not support this feature.
    ret = pm_device_identities_list_set(m_whitelist_peers, m_whitelist_peer_cnt);
    if (ret != NRF_ERROR_NOT_SUPPORTED)
    {
        APP_ERROR_CHECK(ret);
    }

    m_is_wl_changed = false;

    ret = ble_advertising_start(BLE_ADV_MODE_FAST);
    APP_ERROR_CHECK(ret);
}


/**@brief Function for handling Peer Manager events.
 *
 * @param[in] p_evt  Peer Manager event.
 */
static void pm_evt_handler(pm_evt_t const * p_evt)
{
    ret_code_t err_code;

    switch (p_evt->evt_id)
    {
        case PM_EVT_BONDED_PEER_CONNECTED:
        {
            NRF_LOG_INFO("Connected to a previously bonded device.\r\n");
        } break;

        case PM_EVT_CONN_SEC_SUCCEEDED:
        {
            NRF_LOG_INFO("Connection secured. Role: %d. conn_handle: %d, Procedure: %d\r\n",
                         ble_conn_state_role(p_evt->conn_handle),
                         p_evt->conn_handle,
                         p_evt->params.conn_sec_succeeded.procedure);

            m_peer_id = p_evt->peer_id;

            // Note: You should check on what kind of white list policy your application should use.
            if (p_evt->params.conn_sec_succeeded.procedure == PM_LINK_SECURED_PROCEDURE_BONDING)
            {
                NRF_LOG_INFO("New Bond, add the peer to the whitelist if possible\r\n");
                NRF_LOG_INFO("\tm_whitelist_peer_cnt %d, MAX_PEERS_WLIST %d\r\n",
                               m_whitelist_peer_cnt + 1,
                               BLE_GAP_WHITELIST_ADDR_MAX_COUNT);

                if (m_whitelist_peer_cnt < BLE_GAP_WHITELIST_ADDR_MAX_COUNT)
                {
                    // Bonded to a new peer, add it to the whitelist.
                    m_whitelist_peers[m_whitelist_peer_cnt++] = m_peer_id;
                    m_is_wl_changed = true;
                }
            }
        } break;

        case PM_EVT_CONN_SEC_FAILED:
        {
            /* Often, when securing fails, it shouldn't be restarted, for security reasons.
             * Other times, it can be restarted directly.
             * Sometimes it can be restarted, but only after changing some Security Parameters.
             * Sometimes, it cannot be restarted until the link is disconnected and reconnected.
             * Sometimes it is impossible, to secure the link, or the peer device does not support it.
             * How to handle this error is highly application dependent. */
        } break;

        case PM_EVT_CONN_SEC_CONFIG_REQ:
        {
            // Reject pairing request from an already bonded peer.
            pm_conn_sec_config_t conn_sec_config = {.allow_repairing = false};
            pm_conn_sec_config_reply(p_evt->conn_handle, &conn_sec_config);
        } break;

        case PM_EVT_STORAGE_FULL:
        {
            // Run garbage collection on the flash.
            err_code = fds_gc();
            if (err_code == FDS_ERR_BUSY || err_code == FDS_ERR_NO_SPACE_IN_QUEUES)
            {
                // Retry.
            }
            else
            {
                APP_ERROR_CHECK(err_code);
            }
        } break;

        case PM_EVT_PEERS_DELETE_SUCCEEDED:
        {
            advertising_start();
        } break;

        case PM_EVT_LOCAL_DB_CACHE_APPLY_FAILED:
        {
            // The local database has likely changed, send service changed indications.
            pm_local_database_has_changed();
        } break;

        case PM_EVT_PEER_DATA_UPDATE_FAILED:
        {
            // Assert.
            APP_ERROR_CHECK(p_evt->params.peer_data_update_failed.error);
        } break;

        case PM_EVT_PEER_DELETE_FAILED:
        {
            // Assert.
            APP_ERROR_CHECK(p_evt->params.peer_delete_failed.error);
        } break;

        case PM_EVT_PEERS_DELETE_FAILED:
        {
            // Assert.
            APP_ERROR_CHECK(p_evt->params.peers_delete_failed_evt.error);
        } break;

        case PM_EVT_ERROR_UNEXPECTED:
        {
            // Assert.
            APP_ERROR_CHECK(p_evt->params.error_unexpected.error);
        } break;

        case PM_EVT_CONN_SEC_START:
        case PM_EVT_PEER_DATA_UPDATE_SUCCEEDED:
        case PM_EVT_PEER_DELETE_SUCCEEDED:
        case PM_EVT_LOCAL_DB_CACHE_APPLIED:
        case PM_EVT_SERVICE_CHANGED_IND_SENT:
        case PM_EVT_SERVICE_CHANGED_IND_CONFIRMED:
        default:
            break;
    }
}


/**@brief Function for handling Service errors.
 *
 * @details A pointer to this function will be passed to each service which may need to inform the
 *          application about an error.
 *
 * @param[in]   nrf_error   Error code containing information about what went wrong.
 */
static void service_error_handler(uint32_t nrf_error)
{
    APP_ERROR_HANDLER(nrf_error);
}


/**@brief Function for handling advertising errors.
 *
 * @param[in] nrf_error  Error code containing information about what went wrong.
 */
static void ble_advertising_error_handler(uint32_t nrf_error)
{
    APP_ERROR_HANDLER(nrf_error);
}


/**@brief Function for performing a battery measurement, and update the Battery Level characteristic in the Battery Service.
 */
static void battery_level_update(void)
{
    uint32_t err_code;
    uint8_t  battery_level;

    battery_level = 69;

    err_code = ble_bas_battery_level_update(&m_bas, battery_level);
    if ((err_code != NRF_SUCCESS) &&
        (err_code != NRF_ERROR_INVALID_STATE) &&
        (err_code != BLE_ERROR_NO_TX_PACKETS) &&
        (err_code != BLE_ERROR_GATTS_SYS_ATTR_MISSING)
       )
    {
        APP_ERROR_HANDLER(err_code);
    }
}

static void LED_blink(void){
	app_timer_start(m_blink,LED_BLINK_TIME,NULL);
	nrf_gpio_pin_clear(ONBOARD_LED_PIN);
}

/**@brief Function for handling the Battery measurement timer timeout.
 *
 * @details This function will be called each time the battery level measurement timer expires.
 *
 * @param[in]   p_context   Pointer used for passing some arbitrary information (context) from the
 *                          app_start_timer() call to the timeout handler.
 */
static void battery_level_meas_timeout_handler(void * p_context)
{
    UNUSED_PARAMETER(p_context);
    battery_level_update();
}
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
int main(void)
{
    bool     erase_bonds=false;
    // @TODO: figure out how to delete device from peer manager when pair is deleted on a phone/host (MCU thinks its connected so won't go to sleep, neither pair to new device - bonds erasing needed on MCU side)
    uint32_t err_code;


    // Initialize.
    err_code = NRF_LOG_INIT(NULL);
    APP_ERROR_CHECK(err_code);

    gpiote_init();
    mcp2515_init();
    mcp2515_start();
    NRF_LOG_INFO("MCP2515 init - 16Mhz\r\n");

    timers_init();
    ble_stack_init();
    scheduler_init();
    peer_manager_init(erase_bonds);
    if (erase_bonds == true)
    {
        NRF_LOG_INFO("Bonds erased!\r\n");
    }
    gap_params_init();
    advertising_init();
    services_init();
    conn_params_init();

    // Start execution.

    timers_start();
    advertising_start();

    // Enter main loop.
    for (;;)
    {
        app_sched_execute();
        if (NRF_LOG_PROCESS() == false)
        {
            power_manage();
        }
    }
}


/**
 * @}
 */

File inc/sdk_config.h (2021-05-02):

#ifndef SDK_CONFIG_H
#define SDK_CONFIG_H
// <<< Use Configuration Wizard in Context Menu >>>\n
#ifdef USE_APP_CONFIG
#include "app_config.h"
#endif
// <h> nRF_BLE 

//==========================================================
// <q> BLE_ADVERTISING_ENABLED  - ble_advertising - Advertising module
 

#ifndef BLE_ADVERTISING_ENABLED
#define BLE_ADVERTISING_ENABLED 1
#endif

// <q> BLE_DTM_ENABLED  - ble_dtm - Module for testing RF/PHY using DTM commands
 

#ifndef BLE_DTM_ENABLED
#define BLE_DTM_ENABLED 0
#endif

// <q> BLE_RACP_ENABLED  - ble_racp - Record Access Control Point library
 

#ifndef BLE_RACP_ENABLED
#define BLE_RACP_ENABLED 0
#endif

// <q> NRF_BLE_QWR_ENABLED  - nrf_ble_qwr - Queued writes support module (prepare/execute write)
 

#ifndef NRF_BLE_QWR_ENABLED
#define NRF_BLE_QWR_ENABLED 0
#endif

// <q> PEER_MANAGER_ENABLED  - peer_manager - Peer Manager
 

#ifndef PEER_MANAGER_ENABLED
#define PEER_MANAGER_ENABLED 1
#endif

// </h> 
//==========================================================

// <h> nRF_BLE_Services 

//==========================================================
// <q> BLE_ANCS_C_ENABLED  - ble_ancs_c - Apple Notification Service Client
 

#ifndef BLE_ANCS_C_ENABLED
#define BLE_ANCS_C_ENABLED 0
#endif

// <q> BLE_ANS_C_ENABLED  - ble_ans_c - Alert Notification Service Client
 

#ifndef BLE_ANS_C_ENABLED
#define BLE_ANS_C_ENABLED 0
#endif

// <q> BLE_BAS_C_ENABLED  - ble_bas_c - Battery Service Client
 

#ifndef BLE_BAS_C_ENABLED
#define BLE_BAS_C_ENABLED 0
#endif

// <q> BLE_BAS_ENABLED  - ble_bas - Battery Service
 

#ifndef BLE_BAS_ENABLED
#define BLE_BAS_ENABLED 1
#endif

// <q> BLE_CSCS_ENABLED  - ble_cscs - Cycling Speed and Cadence Service
 

#ifndef BLE_CSCS_ENABLED
#define BLE_CSCS_ENABLED 0
#endif

// <q> BLE_CTS_C_ENABLED  - ble_cts_c - Current Time Service Client
 

#ifndef BLE_CTS_C_ENABLED
#define BLE_CTS_C_ENABLED 0
#endif

// <q> BLE_DIS_ENABLED  - ble_dis - Device Information Service
 

#ifndef BLE_DIS_ENABLED
#define BLE_DIS_ENABLED 1
#endif

// <q> BLE_GLS_ENABLED  - ble_gls - Glucose Service
 

#ifndef BLE_GLS_ENABLED
#define BLE_GLS_ENABLED 0
#endif

// <q> BLE_HIDS_ENABLED  - ble_hids - Human Interface Device Service
 

#ifndef BLE_HIDS_ENABLED
#define BLE_HIDS_ENABLED 1
#endif

// <e> BLE_HRS_C_ENABLED - ble_hrs_c - Heart Rate Service Client
//==========================================================
#ifndef BLE_HRS_C_ENABLED
#define BLE_HRS_C_ENABLED 0
#endif
#if  BLE_HRS_C_ENABLED
// <o> BLE_HRS_C_RR_INTERVALS_MAX_CNT - Maximum number of RR_INTERVALS per notification to be decoded 
#ifndef BLE_HRS_C_RR_INTERVALS_MAX_CNT
#define BLE_HRS_C_RR_INTERVALS_MAX_CNT 30
#endif

#endif //BLE_HRS_C_ENABLED
// </e>

// <q> BLE_HRS_ENABLED  - ble_hrs - Heart Rate Service
 

#ifndef BLE_HRS_ENABLED
#define BLE_HRS_ENABLED 0
#endif

// <q> BLE_HTS_ENABLED  - ble_hts - Health Thermometer Service
 

#ifndef BLE_HTS_ENABLED
#define BLE_HTS_ENABLED 0
#endif

// <q> BLE_IAS_C_ENABLED  - ble_ias_c - Immediate Alert Service Client
 

#ifndef BLE_IAS_C_ENABLED
#define BLE_IAS_C_ENABLED 0
#endif

// <q> BLE_IAS_ENABLED  - ble_ias - Immediate Alert Service
 

#ifndef BLE_IAS_ENABLED
#define BLE_IAS_ENABLED 0
#endif

// <q> BLE_LBS_C_ENABLED  - ble_lbs_c - Nordic LED Button Service Client
 

#ifndef BLE_LBS_C_ENABLED
#define BLE_LBS_C_ENABLED 0
#endif

// <q> BLE_LBS_ENABLED  - ble_lbs - LED Button Service
 

#ifndef BLE_LBS_ENABLED
#define BLE_LBS_ENABLED 0
#endif

// <q> BLE_LLS_ENABLED  - ble_lls - Link Loss Service
 

#ifndef BLE_LLS_ENABLED
#define BLE_LLS_ENABLED 0
#endif

// <q> BLE_NUS_C_ENABLED  - ble_nus_c - Nordic UART Central Service
 

#ifndef BLE_NUS_C_ENABLED
#define BLE_NUS_C_ENABLED 0
#endif

// <q> BLE_NUS_ENABLED  - ble_nus - Nordic UART Service
 

#ifndef BLE_NUS_ENABLED
#define BLE_NUS_ENABLED 0
#endif

// <q> BLE_RSCS_C_ENABLED  - ble_rscs_c - Running Speed and Cadence Client
 

#ifndef BLE_RSCS_C_ENABLED
#define BLE_RSCS_C_ENABLED 0
#endif

// <q> BLE_RSCS_ENABLED  - ble_rscs - Running Speed and Cadence Service
 

#ifndef BLE_RSCS_ENABLED
#define BLE_RSCS_ENABLED 0
#endif

// <q> BLE_TPS_ENABLED  - ble_tps - TX Power Service
 

#ifndef BLE_TPS_ENABLED
#define BLE_TPS_ENABLED 0
#endif

// </h> 
//==========================================================

// <h> nRF_Drivers 

//==========================================================
// <e> ADC_ENABLED - nrf_drv_adc - Driver for ADC peripheral (nRF51)
//==========================================================
#ifndef ADC_ENABLED
#define ADC_ENABLED 0
#endif
#if  ADC_ENABLED
// <o> ADC_CONFIG_IRQ_PRIORITY  - Interrupt priority
 

// <i> Priorities 0,2 (nRF51) and 0,1,4,5 (nRF52) are reserved for SoftDevice
// <0=> 0 (highest) 
// <1=> 1 
// <2=> 2 
// <3=> 3 

#ifndef ADC_CONFIG_IRQ_PRIORITY
#define ADC_CONFIG_IRQ_PRIORITY 3
#endif
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

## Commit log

2021-04-04 Working CANbus library and interaction with BLE-HID
2021-04-11 PCB revision 1
    [CANbus-BLEHID.csv, CANbus-BLEHID.kicad_pcb, CANbus-BLEHID.sch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]
2021-04-13 PCB production and assembly files
    [CANbus-BLEHID.kicad_pcb, CANbus-BLEHID.sch]
2021-05-02 power-saving, auto playing after connect, mcp2515 driver improvements
2021-05-22 PCB prototype code update
2021-07-10 erasing bonds with mute+PCB button and minor tweaks
2021-07-11 activity led fix
2022-01-05 added steering wheel button inhibit
2022-04-08 increased steering wheel debouce delay
